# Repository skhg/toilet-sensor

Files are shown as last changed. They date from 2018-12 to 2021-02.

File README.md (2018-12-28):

# toilet-sensor
An Arduino-based toilet cistern monitor.

## Concept
Sometimes the toilet needs an extra flush, and the cistern takes a while to fill up. How full is it? How long should I wait? 

These are important questions.

Finally, we have answers.

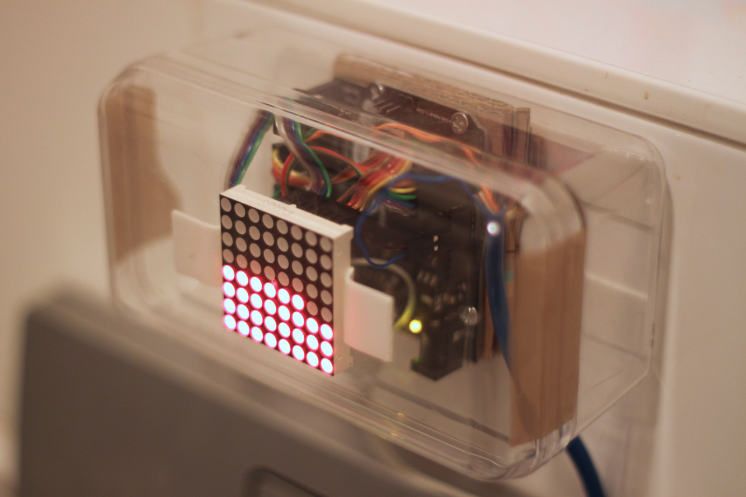
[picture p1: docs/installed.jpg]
Installed sensor


Sensor at work:

Sensor at work

## Overview

An ultrasound distance sensor is installed within the toilet cistern. It emits ultrasound pulses which are reflected from the water surface and indicate the tank fill level. The sensor is controller by an Arduino microcontroller which reads the data, and generates the "image" to be displayed on the connected 8x8 LED matrix.

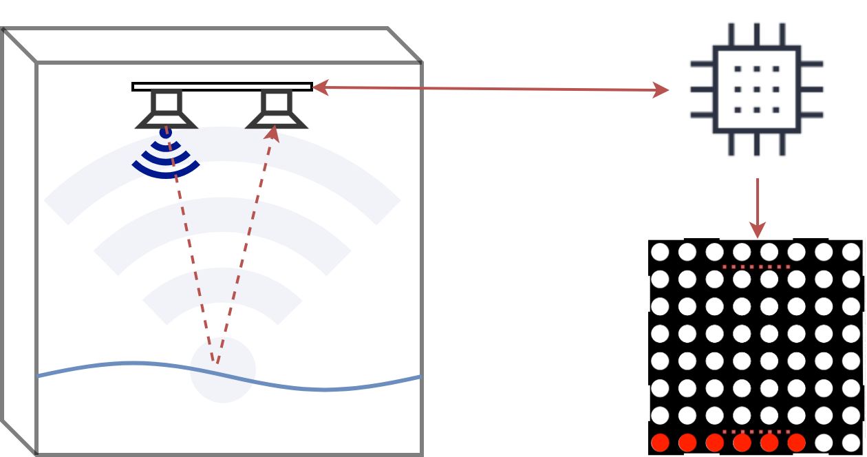
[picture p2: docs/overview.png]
Overview


## Materials required
Electronics:
* 1 Arduino [Leonardo](https://www.amazon.co.uk/gp/product/B00CXFJYPM/ref=oh_aui_detailpage_o01_s03?ie=UTF8&psc=1)
* 1 8x8 LED matrix
* 1 HC-SR04 Ultrasonic distance sensor
* [Ribbon cable](https://www.amazon.de/gp/product/B076CLY8NH/ref=oh_aui_detailpage_o00_s00?ie=UTF8&psc=1)
* [Jumper pin connectors](https://www.amazon.de/gp/product/B01MRSUEHD/ref=oh_aui_detailpage_o01_s00?ie=UTF8&psc=1)
* 1 Ethernet cable
* 1 [Mini breadboard](https://www.amazon.de/gp/product/B01M9CHKO4/ref=oh_aui_detailpage_o01_s00?ie=UTF8&psc=1)
* 1 USB power supply

Other:
* 1 Small plastic box
* Double-sided sticky tape
* Cardboard
* Small screws
* Drill and assorted bits
* Various small pliers, screwdriver, common tools

## Construction
This was done in 2 parts, with the sensor adapter and the display module built seperately

### Sensor
Within the toilet cistern I found that there were 2 removable plastic clips which hold a protective plate onto it's front. Each of these had a small pre-existing hole bored through it, which was ideal for mounting the sensor in the right direction. To this plastic clip I attached an angled piece of metal, and the mini breadboard on the other end. The sensor sits here facing downward and "secured" by a tie-wrap. I cut open an Ethernet cable and used 4 of the inner wires to connect the breadboard.

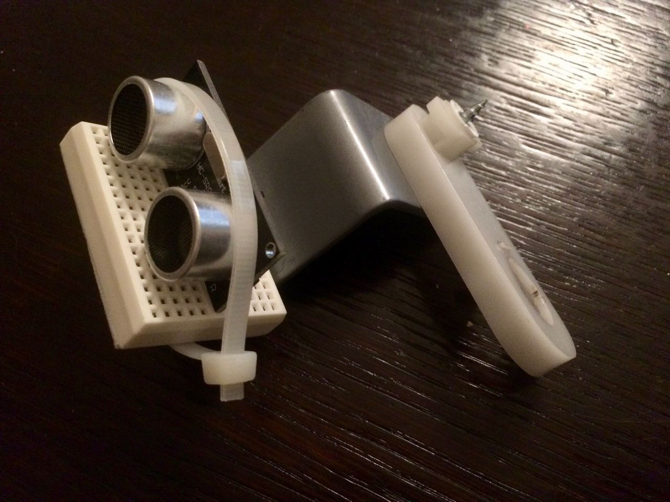
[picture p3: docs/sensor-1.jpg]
Sensor adapter
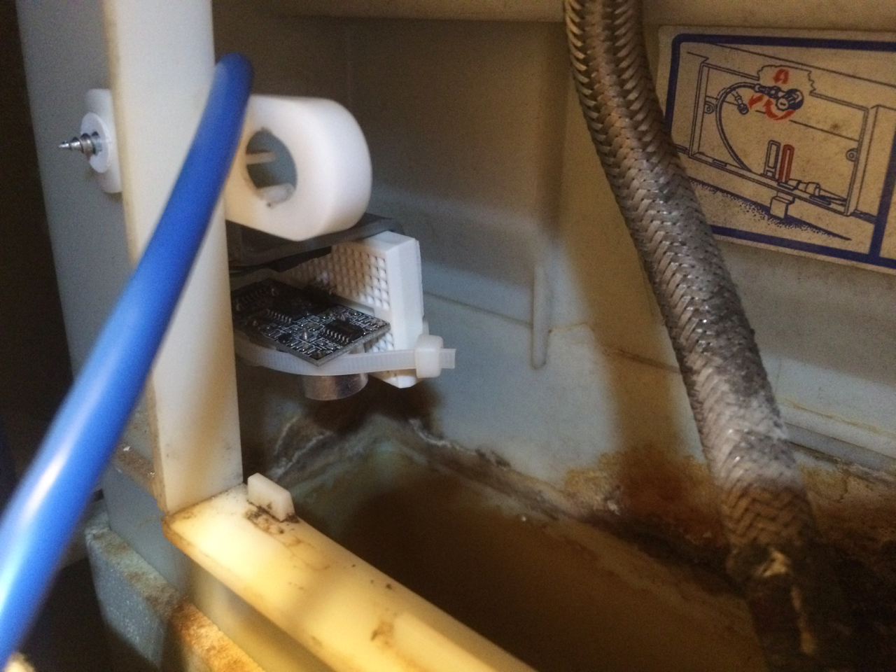
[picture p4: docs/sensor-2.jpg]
Installed - close up
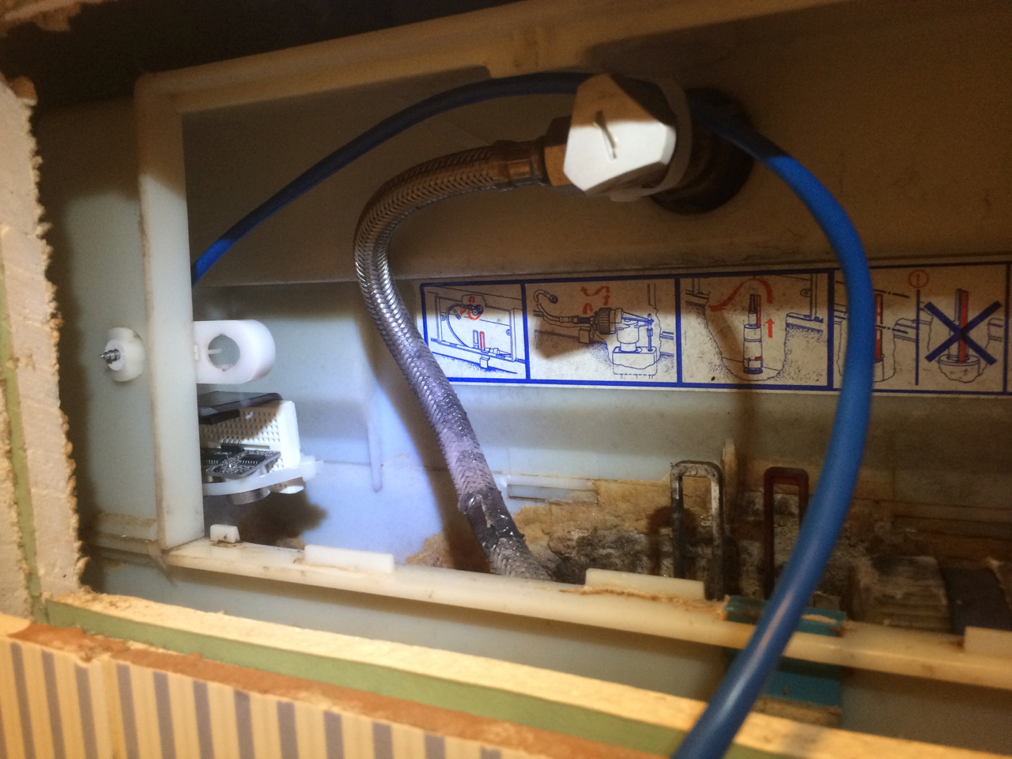
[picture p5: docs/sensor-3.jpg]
Installed - wider view
  

### Display
Initially I prototyped the project using the Ethernet cable trailing out and everything hooked up to a breadboard:

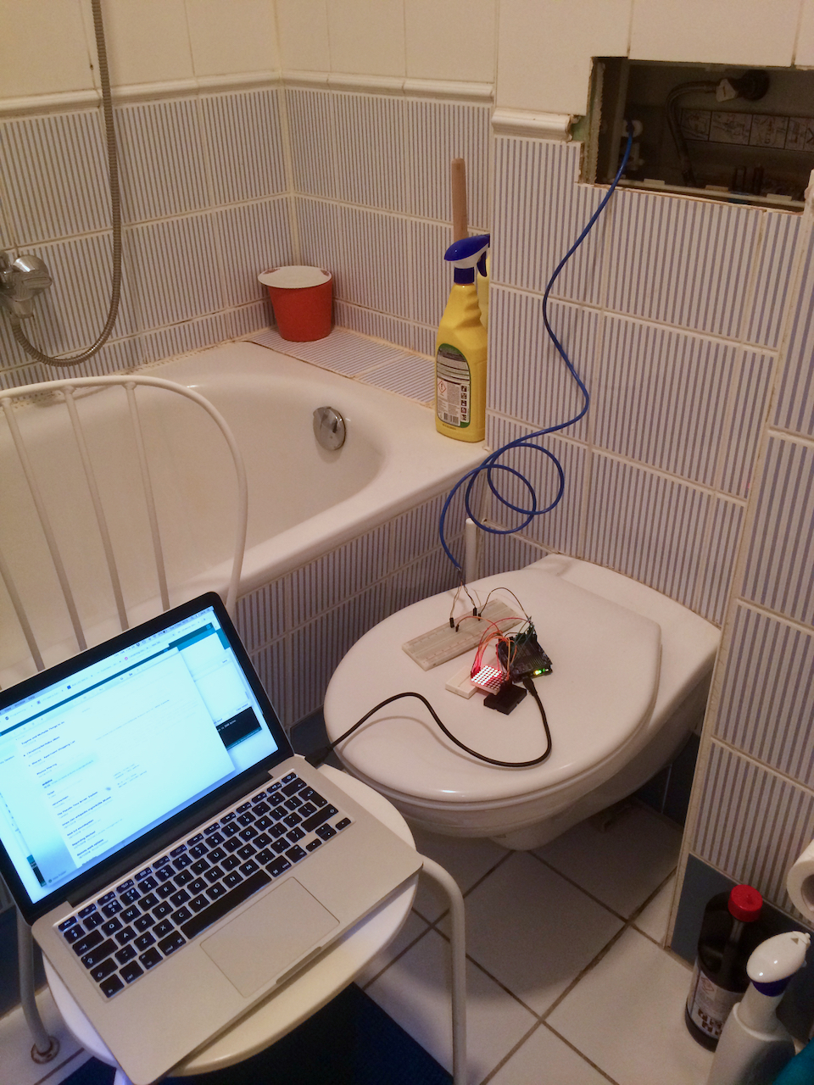
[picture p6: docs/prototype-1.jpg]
Prototype - wide view
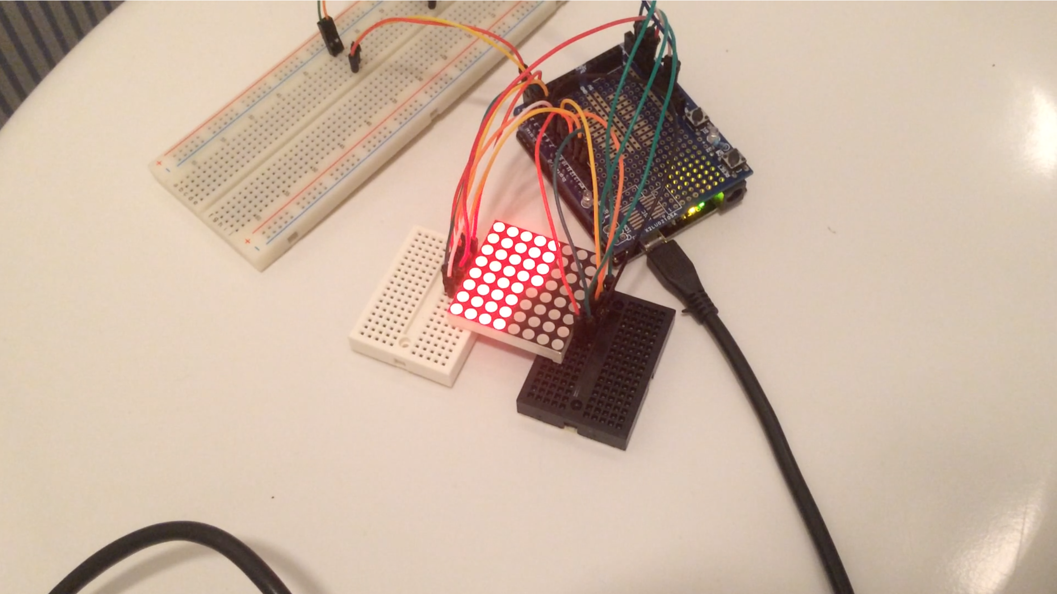
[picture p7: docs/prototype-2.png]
Prototype - close up
 

This was enough to prove the concept worked within the cistern and interference didn't occur with the sides of the tank.

Next I moved on to mounting the components in a case. This was a repurposed 200g [Ferrero Rocher](https://www.amazon.de/Rocher-5er-Pack-200-Packung/dp/B00TYCAR26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) box. I drilled two holes in the bottom (not visible here) large enough to admit the Ethernet cable and micro-USB power supply.

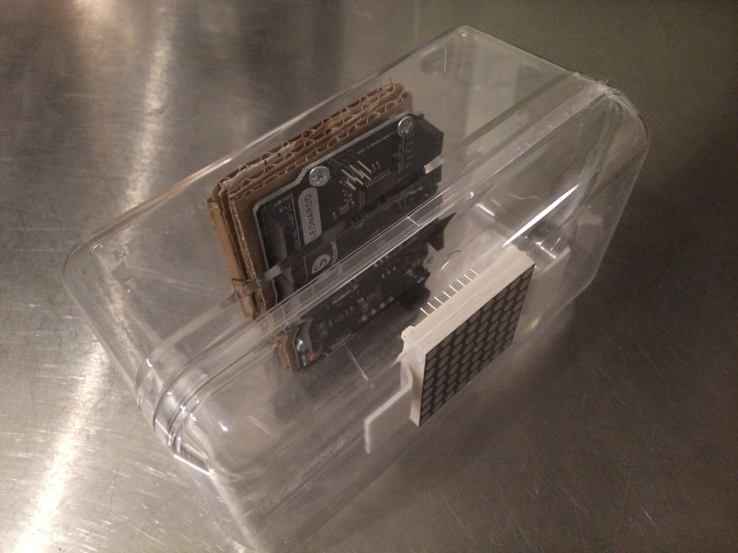
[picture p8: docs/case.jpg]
Case


And connecting them with some 12cm lengths of ribbon cable:

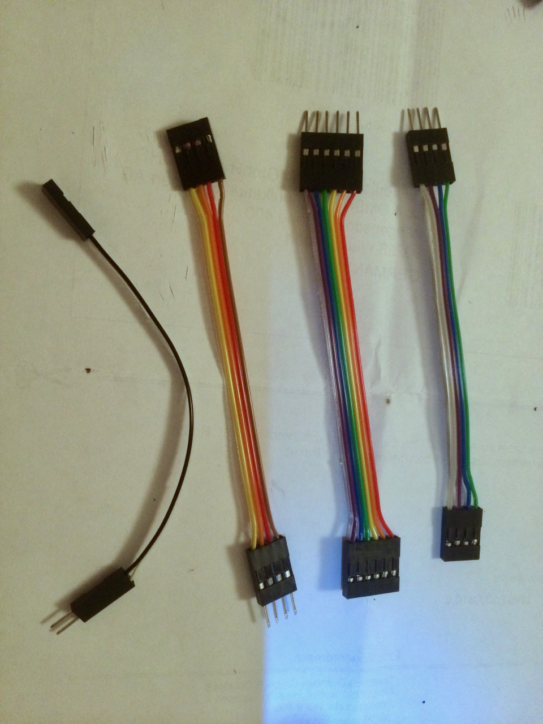
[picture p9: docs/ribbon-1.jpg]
Ribbon cable
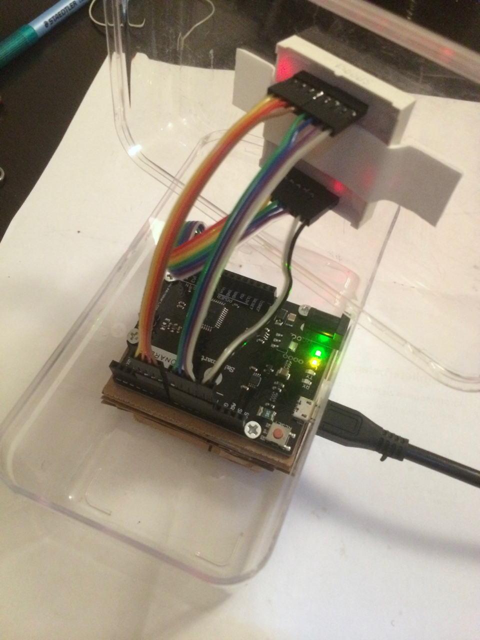
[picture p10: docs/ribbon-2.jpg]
Ribbon cable - in the container
 

And with this complete, I tidied up the wiring, reattached the flush button, mounted the whole unit to the wall, and powered it up:

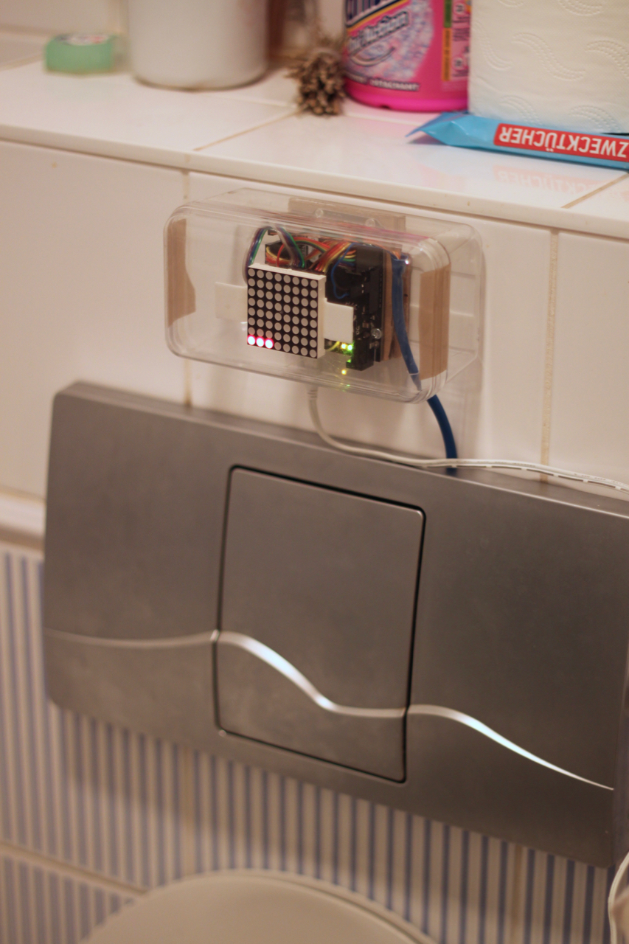
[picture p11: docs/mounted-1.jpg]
Mounted - 1
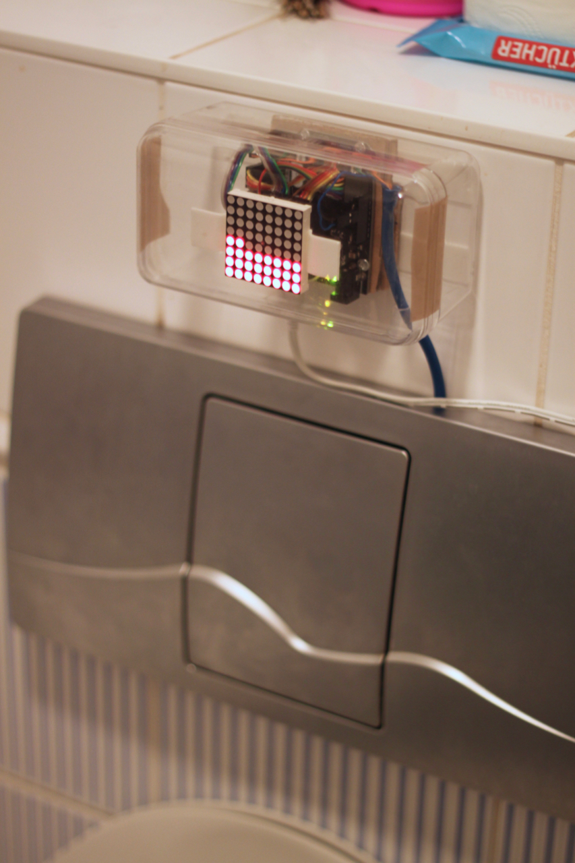
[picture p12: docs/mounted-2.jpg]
Mounted - 2
 

## Code
See the full Arduino C++ code in [toilet-sensor.ino](toilet-sensor.ino). 

## Circuit
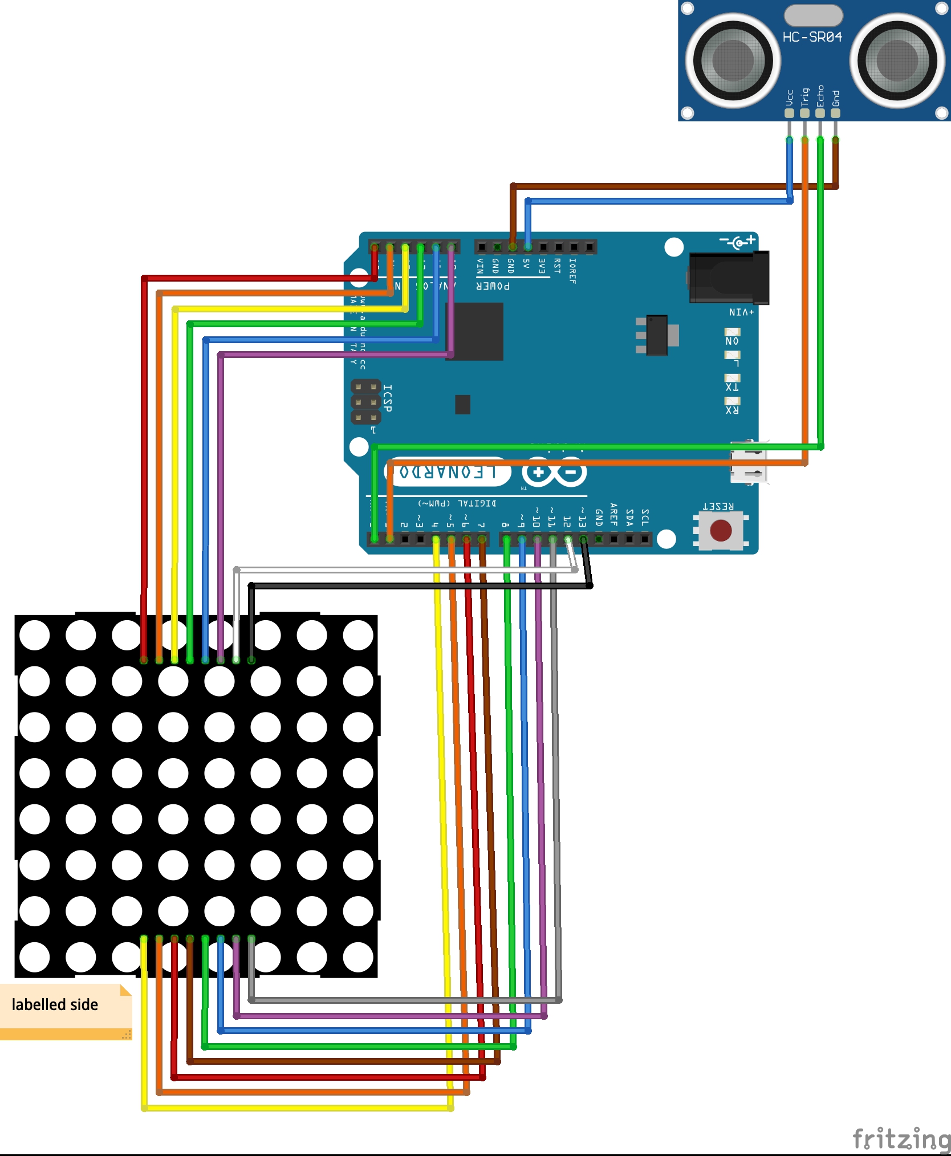
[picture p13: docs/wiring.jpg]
Circuit diagram


This can also be viewed in the [Fritzing](http://fritzing.org/) software using the [diagram.fzz](diagram.fzz) file. 

## Calibration
Once the sensor and display were installed, the readings needed to be calibrated, since there's no way to know exactly how high or low the water level will be in comparison to the test runs (The sensor angle might have shifted during installation, etc). Calibration can be done very easily by capturing the serial output of the Arduino and exporting it to a spreadsheet.

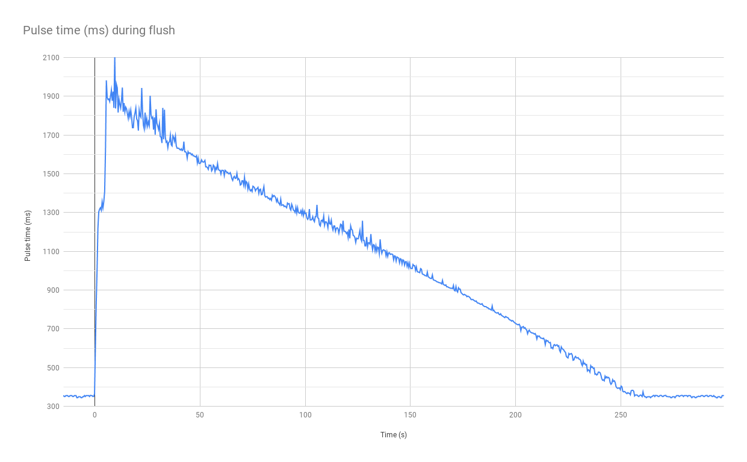
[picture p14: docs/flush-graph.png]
Flush graph


Due to the confined space within the cistern and the natural movement of the water as it refills, the data at the start and end of the refill cycle is quite noisy. Ideally this would be solved by taking higher frequency measurements and smoothing for an average value, but this can come later.

For simplicity, in this example I take the `top` value as `400` and the `bottom` value as `1900`. These values are configured at the top of the code file.

## References
These tutorials and guides proved useful during the project

* [Programming 8x8 LED Matrix](https://create.arduino.cc/projecthub/SAnwandter1/programming-8x8-led-matrix-23475a)
* [Simple Arduino and HC-SR04 Example](https://www.instructables.com/id/Simple-Arduino-and-HC-SR04-Example/)

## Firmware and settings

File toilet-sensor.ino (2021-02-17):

/**
 * Copyright 2019-2021 Jack Higgins : https://github.com/skhg
 * All components of this project are licensed under the MIT License.
 * See the LICENSE file for details.
 * 
 * Portions of this code were sourced from the Arduino Project Hub at:
 * https://create.arduino.cc/projecthub/SAnwandter1/programming-8x8-led-matrix-23475a
 */

// User-defined configuration

// Milliseconds ping time when the cistern is full
#define TOP_MILLIS 380

// Milliseconds ping time when the cistern is empty
#define BOTTOM_MILLIS 1900

// Milliseconds between pings
#define SENSE_DELAY_MILLIS 0

// Milliseconds between display updates
#define DISPLAY_DELAY_MILLIS 20

/** 
 * A fraction of the range between top and bottom. When the fast moving average strays outside 
 * this range (relative to the slow moving average) a flush is detected.
 */
#define FLUSH_FACTOR 25



// System configuration

#include <movingAvg.h>

// 8x8 LED pin locations
#define ROW_1 8
#define ROW_2 5
#define ROW_3 10
#define ROW_4 4
#define ROW_5 A1
#define ROW_6 11
#define ROW_7 A3
#define ROW_8 13
#define COL_1 A2
#define COL_2 6
#define COL_3 7
#define COL_4 12
#define COL_5 9
#define COL_6 A0
#define COL_7 A4
#define COL_8 A5

// Ultrasound sensor pin locations
#define TRIGGER_PIN 1
#define ECHO_PIN 0

// Pixel locations
const byte rows[] = {
  ROW_1, ROW_2, ROW_3, ROW_4, ROW_5, ROW_6, ROW_7, ROW_8
};
const byte col[] = {
  COL_1, COL_2, COL_3, COL_4, COL_5, COL_6, COL_7, COL_8
};

const byte EMPTY[] = {
  B00000000,
  B00000000,
  B00000000,
  B00000000,
  B00000000,
  B00000000,
  B00000000,
  B00000000
};

const byte CHECK_MARK[] = {
  B00000000,
  B00000001,
  B00000010,
  B00000100,
  B10001000,
  B01010000,
  B00100000,
  B00000000
};

int _cyclesSinceLastPulse = 0;
int _cyclesSinceLastDisplayUpdate = 0;
int _displayedValue = 0;
const int _range = BOTTOM_MILLIS - TOP_MILLIS;

movingAvg SLOW_AVG(1000);
movingAvg FAST_AVG(50);

void setup() {
  Serial.begin(9600);
  pinMode(TRIGGER_PIN, OUTPUT);
  pinMode(ECHO_PIN, INPUT);

  // Setup screen
  for (byte i = 2; i <= 13; i++) {
    pinMode(i, OUTPUT);
  }

  pinMode(A0, OUTPUT);
  pinMode(A1, OUTPUT);
  pinMode(A2, OUTPUT);
  pinMode(A3, OUTPUT);
  pinMode(A4, OUTPUT);
  pinMode(A5, OUTPUT);

  SLOW_AVG.begin();
  FAST_AVG.begin();
}

void loop() {
  takeReading();
  chooseDisplayableValue();
  updateDisplay(_displayedValue);
}

/**
 * During a flush, we want to update the level more frequently. We can choose to use
 * the less accurate "fast" moving average for this.
 */
void chooseDisplayableValue() {
  if (_cyclesSinceLastDisplayUpdate > DISPLAY_DELAY_MILLIS) {
    if (detectFlush()) {
      _displayedValue = FAST_AVG.getAvg();
    } else {
      _displayedValue = SLOW_AVG.getAvg();
    }
    _cyclesSinceLastDisplayUpdate = 0;
  } else {
    _cyclesSinceLastDisplayUpdate++;
  }
}

bool detectFlush() {
  int fastAvg = FAST_AVG.getAvg();
  int slowAvg = SLOW_AVG.getAvg();

  return fastAvg > slowAvg && fastAvg > (slowAvg + flushBound());
}

/**
 * Take a reading when needed in the cycle, print the latest value and that of the moving
 * averages, useful for calibration/debugging purposes
 */
void takeReading() {
  if (_cyclesSinceLastPulse > SENSE_DELAY_MILLIS) {
    int duration = sense();
    FAST_AVG.reading(duration);
    SLOW_AVG.reading(duration);

    print_info(duration, FAST_AVG, SLOW_AVG);

    _cyclesSinceLastPulse = 0;
  } else {
    _cyclesSinceLastPulse++;
  }
}

void updateDisplay(int duration) {
  if (inRange(duration)) {
    byte pixels[8];
    renderFillLevel(duration, pixels);
    drawScreen(pixels);
  } else if (isEmpty(duration)) {
    drawScreen(EMPTY);
  } else if (isFull(duration)) {
    drawScreen(CHECK_MARK);
  }
}

/**
 * Converts the level value to a pixel array
 */
void renderFillLevel(int duration, byte *toDraw) {
  double relativeFill = BOTTOM_MILLIS - duration;
  double fractionalFill = relativeFill / _range;
  int filledPixels = fractionalFill * 64;

  buildDots(toDraw, filledPixels);
}

void print_info(int duration, movingAvg avg_short, movingAvg avg_long) {
  Serial.print(duration);
  Serial.print(",");
  Serial.print(avg_short.getAvg());
  Serial.print(",");
  Serial.print(avg_long.getAvg());
  Serial.print(",");
  Serial.print(avg_long.getAvg() + flushBound());
  Serial.print(",");
  Serial.println(avg_long.getAvg() - flushBound());
}

int flushBound() {
  return _range / FLUSH_FACTOR;
}

bool inRange(int duration) {
  return !isEmpty(duration) && !isFull(duration);
}

bool isEmpty(int duration) {
  return duration > BOTTOM_MILLIS;
}

bool isFull(int duration) {
  return duration < TOP_MILLIS;
}

int sense() {
  digitalWrite(TRIGGER_PIN, LOW);
  delayMicroseconds(2);
  digitalWrite(TRIGGER_PIN, HIGH);
  delayMicroseconds(10);
  digitalWrite(TRIGGER_PIN, LOW);
  return pulseIn(ECHO_PIN, HIGH);
}

void buildDots(byte *screen, int count) {
  byte ROWS[] = {
    B00000000,
    B00000000,
    B00000000,
    B00000000,
    B00000000,
    B00000000,
    B00000000,
    B00000000
  };

  byte FILLER[] = {
    B00000000,
    B10000000,
    B11000000,
    B11100000,
    B11110000,
    B11111000,
    B11111100,
    B11111110,
    B11111111
  };

  // Fill rows bottom to top, as a real toilet does
  for (int i = 7; i >= 0; i--) {
    if (count >= 8) {
      ROWS[i] = FILLER[8];
      count = count - 8;
    } else {
      ROWS[i] = FILLER[count];
      count = 0;
    }
  }

  copyScreenContents(ROWS, screen);
}

void copyScreenContents(byte *source, byte *dest) {
  for (int i = 0; i < 8; i++) {
    dest[i] = source[i];
  }
}

/**
 * Originally from:
 * https://create.arduino.cc/projecthub/SAnwandter1/programming-8x8-led-matrix-23475a
 */
void drawScreen(const byte pixelBuffer[]) {
  // Turn on each row in series
  for (byte i = 0; i < 8; i++) {        // count next row
    digitalWrite(rows[i], HIGH);    // initiate whole row
    for (byte a = 0; a < 8; a++) {    // count next row
      digitalWrite(col[a], (~pixelBuffer[i] >> a) & 0x01);  // initiate the col

      delayMicroseconds(50);

      digitalWrite(col[a], 1);      // reset whole column
    }
    digitalWrite(rows[i], LOW);     // reset whole row
    // otherwise last row will intersect with next row
  }
}

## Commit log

2018-12-14 fix fill level display rows and cleanup
    [toilet-sensor.ino]
2018-12-16 correct wire colors
    [diagram.fzz]
2018-12-17 add 3 sensor photos
2018-12-17 prototype images
2018-12-17 add ribbon cable
2018-12-17 add case pic
2018-12-17 add 2 mounted images
2018-12-18 data from sensor at high resolution
    [toilet_highres.csv]
2018-12-18 python notebook for analysis
    [toilet_highres.csv]
2018-12-28 Added Toilet Sensor.xml
2020-11-25 Linting action (#2)
    * linting action
    * remove wifi library
    * fix paths
    * linter fixes
    [toilet-sensor.ino]
2021-02-17 Smoothed average value, and code cleanup (#4)
    * copy code from other branch
    * rename vars and costs for clarity
    * moving avg library in workflow
    * remove unused X drawing
    * clarifying comment and rename var
    * refactor methods for clarity in loop()
    * comments
    * improve flush detection
    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
    [toilet-sensor.ino]
